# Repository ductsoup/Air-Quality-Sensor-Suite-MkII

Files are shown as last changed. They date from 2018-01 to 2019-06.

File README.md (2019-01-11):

# Air-Quality-Sensor-Suite-MkII
A simple, inexpensive but accurate air quality monitor built around a Raspberry Pi 3 or Pi Zero W with the ability to inteface with industrial SCADA systems via Modbus TCP. With a few additional lines of code in the main loop it's relatively straightfoward to push the entire collected and calculated data set to an IoT/IIoT MQTT broker.

The two attached sensors read temperature, pressure, humidity, VOC and particulates. The script then derives other quantities such as dewpoint, air density, air quality index (AQI), NowCast and indoor air quality (IAQ).

## Usage Notes
While tested on Raspian Jessie and Python3 it will probably run on older versions of Python or newer versions of Raspbian with little or no modification.

```sudo python3 main.py```

By default the Modbus slave binds to all active connections. Root privledges are
requred because we're serving on the Modbus default port 502.

As a practical matter you'll probably want to set this script up to run as a service 
with systemd rather than using cron or rc.local. 

* https://www.raspberrypi.org/documentation/linux/usage/systemd.md
* https://github.com/joan2937/pigpio/tree/master/util

## Requirements

### Modbus-tk
https://github.com/ljean/modbus-tk

This provides the MODBUS TCP transport. Values are mapped into holding registeres encoded as an [IEEE 754 32-bit float](https://en.wikipedia.org/wiki/IEEE_754).

If you'd like to send the data to an MQTT broker instead just install Paho and modify the relevant sections in ```main.py```.

### Pigpio
http://abyz.me.uk/rpi/pigpio/index.html

This is used to bitbang GPIO 18 to interface with the PMS5003, just pick another pin if that's inconvenient. 

### Pimoroni BME680
https://github.com/pimoroni/bme680

I'm using an Adafruit breakout board with the Pimoroni library for their breakout board. Both boards are functionally identical, the only relevant difference between them (other than the pinouts) is the default I2C address so I need to specify that when I create the instance.

```bme680.BME680(i2c_addr=0x77)```

## Sensors/Interfaces
### BME680 (I2C) 
* [datasheet](https://cdn-shop.adafruit.com/product-files/3660/BME680.pdf)
* https://shop.pimoroni.com/products/bme680
* https://www.adafruit.com/product/3660

### PMS5003 (software serial)
* [datasheet](https://cdn-shop.adafruit.com/product-files/3686/plantower-pms5003-manual_v2-3.pdf)
* https://www.adafruit.com/product/3686

The original design used a PPD42NS or SM-PWM-01A particle sensor which was difficult to interface with anything but an embedded device because you really need hardware interrupts to count the particles in real time. The PMS5003 does all that internally, reports in engineering units and provides a 3.3V compatible serial output making it very easy to interface with a Raspberry Pi.

![wiring](/img/aqm-mk-II_bb1.jpg)

## MODBUS Register Map
### System
```
40001   Quality Control (3.14159265359)
```
### Measured BME680
```
40003   Temperature (C)
40005   Temperature (F)
40007   Pressure (hPa)
40009   Pressure (inHg)
40011   Relative Humidity (%)
40013   VOC (kOhm)
```
### Measured PMS5003
```
40015   PM1.0 standard (ug/m3)
40017   PM2.5 standard (ug/m3)
40019   PM10 standard (ug/m3)
40021   PM1.0 environmental (ug/m3)
40023   PM2.5 environmental (ug/m3)
40025   PM10 environmental (ug/m3)
40027   Particles > 0.3 um / 0.1L air
40029   Particles > 0.5 um / 0.1L air
40031   Particles > 1.0 um / 0.1L air
40033   Particles > 2.5 um / 0.1L air
40035   Particles > 5.0 um / 0.1L air
40037   Particles > 50  um / 0.1L air
```
### Derived
```
40039   Dewpoint (C)
40041   Dewpoint (F)
40043   Partial pressure water vapor (hPa)
40045   Partial pressure dry air (hPa)
40047   Air density (kg/m3)
40049   Air density (lb/ft3)

40051   AQI (0-500, -1 if unavailable)
40053   PM25 contribution to AQI
40055   PM10 contribution to AQI
40057   AQI NowCast
40059   PM25 contribution to AQI NowCast
40061   PM10 contribution to AQI NowCast
40063   AQI Current (1 minute)
40065   PM25 contribution to AQI Current
40067   PM10 contribution to AQI Current

40069   PM01 60 second average (ug/m3)
40071   PM01 60 minute average (ug/m3)
40073   PM01 24 hour average (ug/m3)
40075   PM25 60 second average (ug/m3)
40077   PM25 60 minute average (ug/m3)
40079   PM25 24 hour average (ug/m3)
40081   PM10 60 second average (ug/m3)
40083   PM10 60 minute average (ug/m3)
40085   PM10 24 hour average (ug/m3)

40087   IAQ (0-100, -1 if unavailable)
40089   RH contribution to IAQ
40091   VOC contribution to IAQ
40093   VOC 60 second average (kOhm)
40095   VOC 60 minute average (kOhm)
40097   VOC 24 hour average (kOhm)
```
## Classes
### Unit Conversion
Weather calculations are notorious for mixing SI and imperial units and combining constants making them difficult to follow. Even with SI it's not uncommon to switch back and forth between units like Celsius and Kelvin.

To simplify, pass an SI value (Celsius) when you initialize a unit conversion object. You can then retrieve the value in any relavant unit, SI or imperial (Celsius, Kelvin, Fahrenheit or Rankine).

```python
Temperature = T(25)
print(Temperature.C, Temperature.K, Temperature.F, Temperature.R)
```
There are also unit conversion classes for pressure and density.

### Cascadable Running/Retained Average 
The first challenge is that AQI requires a 24 hour average measurement and embedded systems can rest at any time. The second is if you're sampling at 1 second intervals that's 86400 (60*60*24) samples to average.

This class allows you to define a one second sample aggregated to a one minute average, cascaded to a one hour average, cascaded to a one day average (lather, rise and repeat for weekly, monthly or annual), writing the results to storage and reloading as necessary between resets. In the 24 hour example it only retains 144 values (60+60+24). As you're building history to whatever average you've defined, the class will provide the best approximation available.

The caveat with SD storage is you have a finite number of write cycles. To start I've chosen the compromise of writing hourly. If the reset is short duration, it won't significantly compromise the results. 

```python
pm25_24h = CRR_AVG(24, jfile = "pm25_24h")    # daily average (retained)
pm25_60m = CRR_AVG(60, pm25_24h)              # hourly average
pm25_60s = CRR_AVG(60, pm25_60m)              # minutely average
```

### Derived Weather Variables
This class approximates dewpoint and air density from the BME680 observations.

### AQI Air Quality Index and NowCast
The AQI class implments [Air Quality Index](https://en.wikipedia.org/wiki/Air_quality_index) and 
[NowCast](https://en.wikipedia.org/wiki/NowCast_(air_quality_index)) calculations. Not defined in those standards but useful for what I'm doing I've also implemented a one minute AQI. 

Currently the class implements only the PM2.5 and PM10 components of AQI. It is however, designed to be easily extended to include O3, CO, SO2 and No2.

### IAQ Indoor Air Quality
There isn't a generally accepted standard for indoor air quality that I am aware of however, Bosch has provided a closed source binary called [BSEC](https://www.bosch-sensortec.com/bst/products/all_products/BSEC) for use with the BME680 to do that calculation. Based on the description in the datasheet they're likely doing something similar to what is implemented in the IAQ class. 

## Enclosure
For the enclosure I customized [The Ultimate box maker](https://www.thingiverse.com/thing:1264391) from Thingiverse.

My 3D printer didn't do such a good job on the 2.05mm tap drill holes for mounting the Pi Zero W and I'm guessing most others won't either so I opened those up with a 5/64 (1.98mm) drill, ran a M2.5x0.45 tap through by hand then finished up with some M2.5 nylon screws (Amazon is your friend for fine tools and supplies like this).

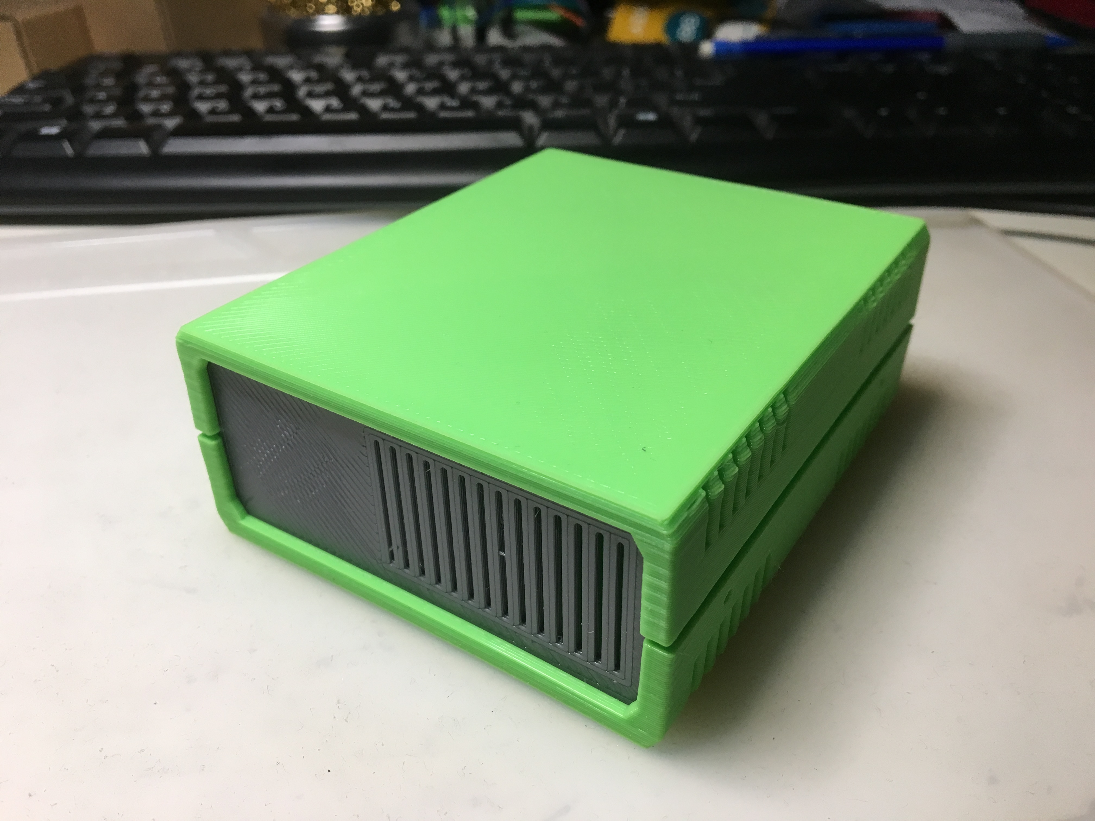
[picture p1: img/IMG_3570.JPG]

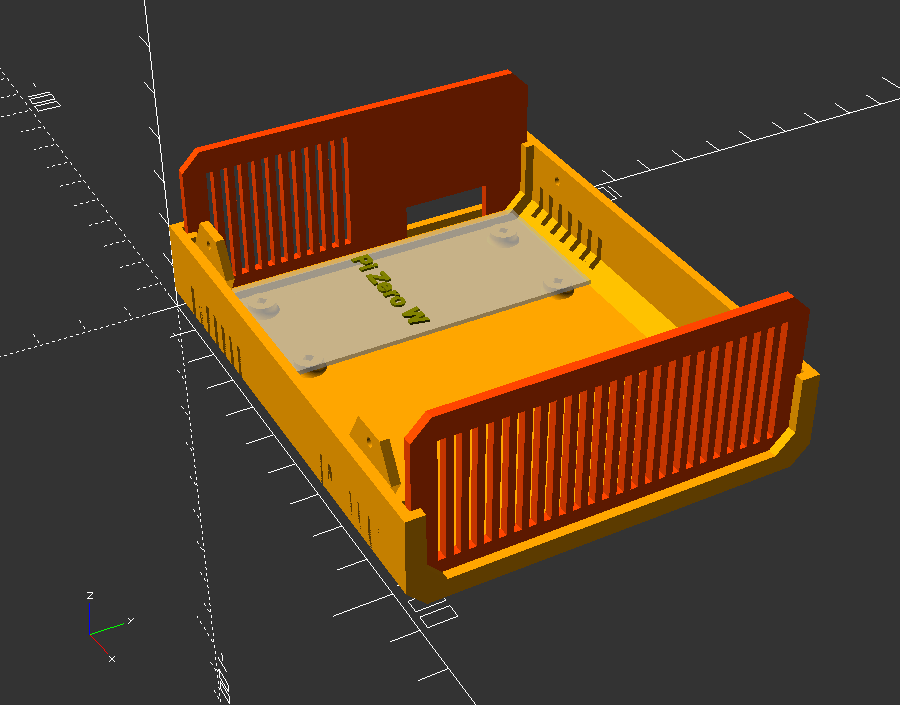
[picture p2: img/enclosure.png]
enclosure


## Rev 1 10/09/2018
I added support for the SGP30 VOC and eCO2 sensor.

### SGP30 (I2C) 
* [datasheet](https://cdn-learn.adafruit.com/assets/assets/000/050/058/original/Sensirion_Gas_Sensors_SGP30_Datasheet_EN.pdf)
* https://www.adafruit.com/product/3709

I also added Eagle files for a custom Pi Hat which I've built a couple times so it's verified good (Sunstone).

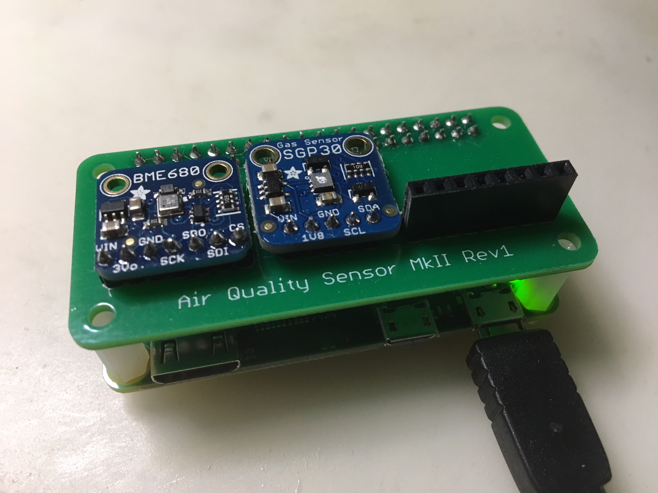
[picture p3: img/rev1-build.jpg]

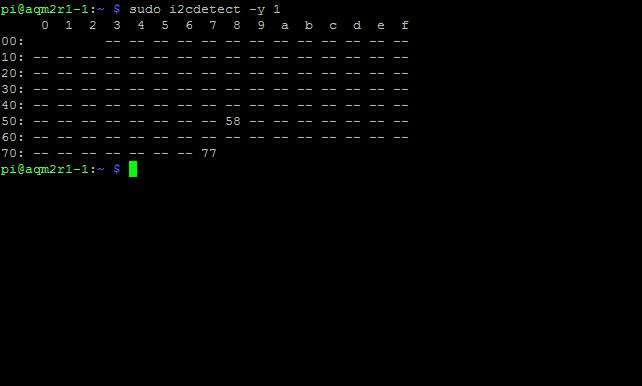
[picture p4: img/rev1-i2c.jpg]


The perma-proto board construction above works great but it's a little tedious and somewhat error prone to build. Populating the custom PCB is easy. It's actually taking far longer to 3D print the enclosure than do the build and configure the software on the Pi Zero W.

```
40099   CO2 equivalent (ppm)
40101   CO2 equivalent 60 second average (ppm)
40103   CO2 equivalent 60 minute average (ppm)
40105   CO2 equivalent 24 hour average (ppm)
40107   VOC (ppb)
40109   VOC 60 second average (ppb)
40111   VOC 60 minute average (ppb)
40113   VOC 24 hour average (ppb)  
40115   Absolute Humidity (g/m^3)
```

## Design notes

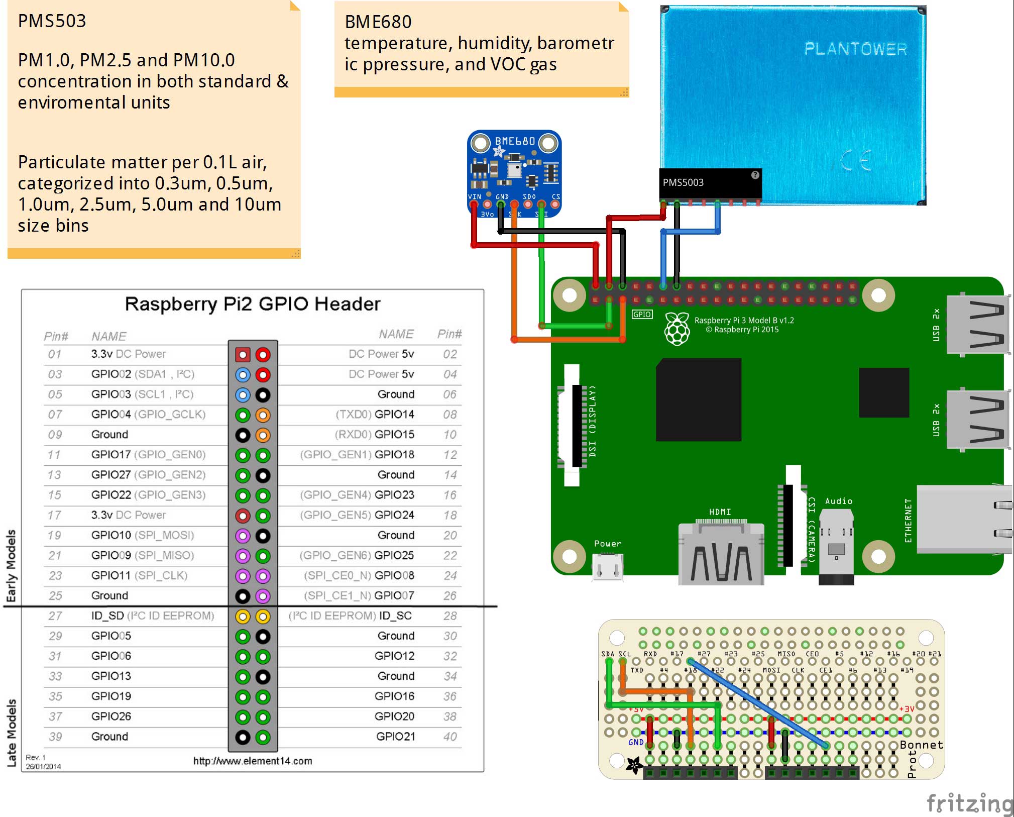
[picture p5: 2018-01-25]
img/aqm-mk-II_bb1.jpg

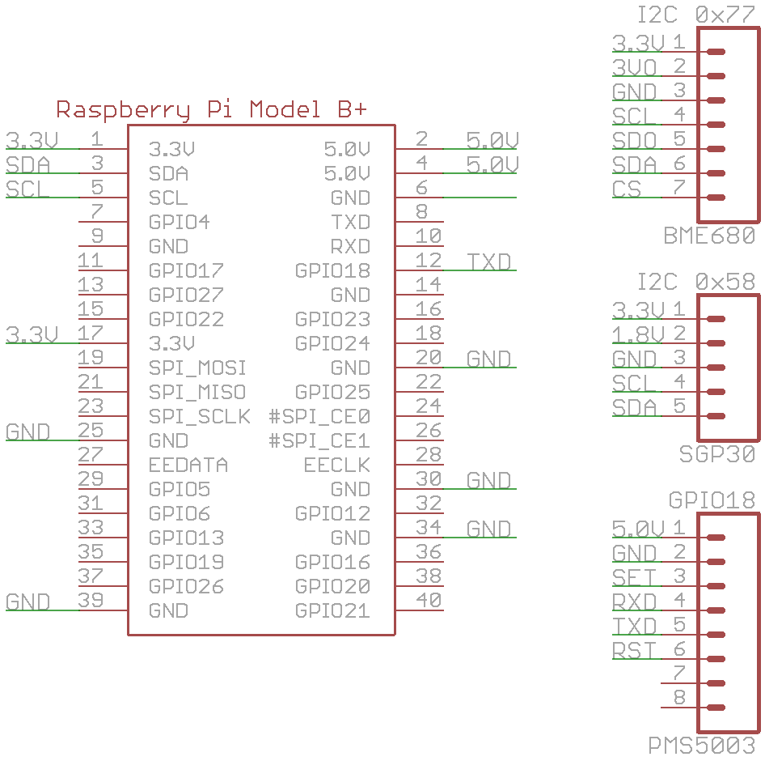
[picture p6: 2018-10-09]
rev1/pcb/sch.png

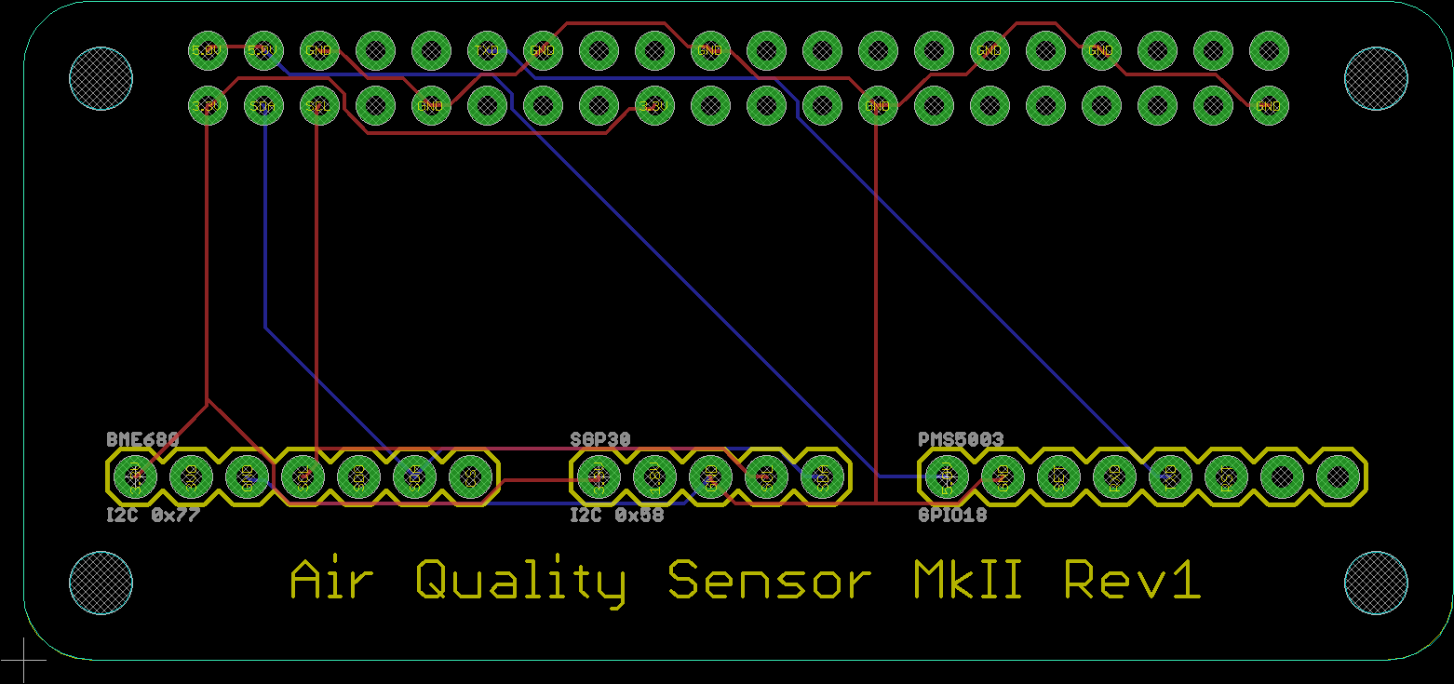
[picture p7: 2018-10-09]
rev1/pcb/brd.png

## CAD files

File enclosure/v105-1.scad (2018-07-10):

/*//////////////////////////////////////////////////////////////////
              -    FB Aka Heartman/Hearty 2016     -                   
              -   http://heartygfx.blogspot.com    -                  
              -       OpenScad Parametric Box      -                     
              -         CC BY-NC 3.0 License       -                      
////////////////////////////////////////////////////////////////////                                                                                                             
12/02/2016 - Fixed minor bug 
28/02/2016 - Added holes ventilation option                    
09/03/2016 - Added PCB feet support, fixed the shell artefact on export mode. 
21/11/2017 by Richard Pillay - Added ability to have up to 4 PCBs

*/////////////////////////// - Info - //////////////////////////////

// All coordinates are starting as integrated circuit pins.
// From the top view :

//   CoordD           <---       CoordC
//                                 ^
//                                 ^
//                                 ^
//   CoordA           --->       CoordB


////////////////////////////////////////////////////////////////////


////////// - Paramètres de la boite - Box parameters - /////////////

/* [Box dimensions] */
// - Longueur - Length  
  Length        = 105;       
// - Largeur - Width
  Width         = 85;                     
// - Hauteur - Height  
  Height        = 40;  
// - Epaisseur - Wall thickness  
  Thick         = 2;//[2:5]  
  
/* [Box options] */
// - Diamètre Coin arrondi - Filet diameter  
  Filet         = 4;//[0.1:12] 
// - lissage de l'arrondi - Filet smoothness  
  Resolution    = 4;//[1:100] 
// - Tolérance - Tolerance (Panel/rails gap)
  m             = 0.9;
// Pieds PCB - PCB feet (x4 for each) 
  PCB01Feet       = 1;// [0:No, 1:Yes]
  PCB02Feet       = 0;// [0:No, 1:Yes]
  PCB03Feet       = 0;// [0:No, 1:Yes]
  PCB04Feet       = 0;// [0:No, 1:Yes]
// - Decorations to ventilation holes
  Vent          = 1;// [0:No, 1:Yes]
// - Decoration-Holes width (in mm)
  Vent_width    = 1.5;   


  
/* [PCB_Feet] */
//All dimensions are from the center foot axis

PCB01Text = "     Pi Zero W";
// - Coin bas gauche - Low left corner X position
PCB01PosX         = 0;
// - Coin bas gauche - Low left corner Y position
PCB01PosY         = 2;
// - Longueur PCB01 - PCB01 Length
PCB01Length       = 23;
// - Largeur PCB01 - PCB01 Width
PCB01Width        = 58;
// - Heuteur pied - Feet height
PCB01FootHeight      = 5;
// - Diamètre pied - Foot diameter
PCB01FootDiam         = 6;
// - Diamètre trou - Hole diameter
PCB01FootHole        = 2.5;  

PCB02Text = "PMS";
PCB02PosX           = 35;
PCB02PosY           = 6;
PCB02Length         = 38;
PCB02Width          = 50;
PCB02FootHeight     = 5;
PCB02FootDiam      = 4;
PCB02FootHole        = 2;  
  
PCB03Text = "PCB3";
PCB03PosX           = 95;
PCB03PosY         = 84;
PCB03Length       = 50;
PCB03Width        = 55;
PCB03FootHeight      = 10;
PCB03FootDiam         = 8;
PCB03FootHole        = 3;  
  
PCB04Text = "PCB4";
PCB04PosX         = 75;
PCB04PosY         = 6;
PCB04Length       = 70;
PCB04Width        = 50;
PCB04FootHeight      = 10;
PCB04FootDiam         = 8;
PCB04FootHole        = 3;  
  

/* [STL element to export] */
//Coque haut - Top shell
TShell          = 0;// [0:No, 1:Yes]
//Coque bas- Bottom shell
BShell          = 0;// [0:No, 1:Yes]
//Panneau avant - Front panel
FPanL           = 1;// [0:No, 1:Yes]
//Panneau arrière - Back panel  
BPanL           = 1;// [0:No, 1:Yes]


  
/* [Hidden] */
// - Couleur coque - Shell color  
Couleur1        = "Orange";       
// - Couleur panneaux - Panels color    
Couleur2        = "OrangeRed";    
// Thick X 2 - making decorations thicker if it is a vent to make sure they go through shell
Dec_Thick       = Vent ? Thick*2 : Thick; 
// - Depth decoration
Dec_size        = Vent ? Thick*2 : 0.8;


/////////// - Boitier générique bord arrondis - Generic rounded box - //////////

module RoundBox($a=Length, $b=Width, $c=Height){// Cube bords arrondis
                    $fn=Resolution;            
                    translate([0,Filet,Filet]){  
                    minkowski (){                                              
                        cube ([$a-(Length/2),$b-(2*Filet),$c-(2*Filet)], center = false);
                        rotate([0,90,0]){    
                        cylinder(r=Filet,h=Length/2, center = false);
                            } 
                        }
                    }
                }// End of RoundBox Module

      
////////////////////////////////// - Module Coque/Shell - //////////////////////////////////         

module Coque(){//Coque - Shell  
    Thick = Thick*2;  
    difference(){    
        difference(){//sides decoration
            union(){    
                     difference() {//soustraction de la forme centrale - Substraction Fileted box
                      
                        difference(){//soustraction cube median - Median cube slicer
                            union() {//union               
                            difference(){//Coque    
                                RoundBox();
                                translate([Thick/2,Thick/2,Thick/2]){     
                                        RoundBox($a=Length-Thick, $b=Width-Thick, $c=Height-Thick);
                                        }
                                        }//Fin diff Coque                            
                                difference(){//largeur Rails        
                                     translate([Thick+m,Thick/2,Thick/2]){// Rails
                                          RoundBox($a=Length-((2*Thick)+(2*m)), $b=Width-Thick, $c=Height-(Thick*2));
                                                          }//fin Rails
                                     translate([((Thick+m/2)*1.55),Thick/2,Thick/2+0.1]){ // +0.1 added to avoid the artefact
                                          RoundBox($a=Length-((Thick*3)+2*m), $b=Width-Thick, $c=Height-Thick);
                                                    }           
                                                }//Fin largeur Rails
                                    }//Fin union                                   
                               translate([-Thick,-Thick,Height/2]){// Cube à soustraire
                                    cube ([Length+100, Width+100, Height], center=false);
                                            }                                            
                                      }//fin soustraction cube median - End Median cube slicer
                               translate([-Thick/2,Thick,Thick]){// Forme de soustraction centrale 
                                    RoundBox($a=Length+Thick, $b=Width-Thick*2, $c=Height-Thick);       
                                    }                          
                                }                                          


                difference(){// wall fixation box legs
                    union(){
                        translate([3*Thick +5,Thick,Height/2]){
                            rotate([90,0,0]){
                                    $fn=6;
                                    cylinder(d=16,Thick/2);
                                    }   
                            }
                            
                       translate([Length-((3*Thick)+5),Thick,Height/2]){
                            rotate([90,0,0]){
                                    $fn=6;
                                    cylinder(d=16,Thick/2);
                                    }   
                            }

                        }
                            translate([4,Thick+Filet,Height/2-57]){   
                             rotate([45,0,0]){
                                   cube([Length,40,40]);    
                                  }
                           }
                           translate([0,-(Thick*1.46),Height/2]){
                                cube([Length,Thick*2,10]);
                           }
                    } //Fin fixation box legs
            }

        union(){// outbox sides decorations
            
            for(i=[0:Thick:Length/4]){
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

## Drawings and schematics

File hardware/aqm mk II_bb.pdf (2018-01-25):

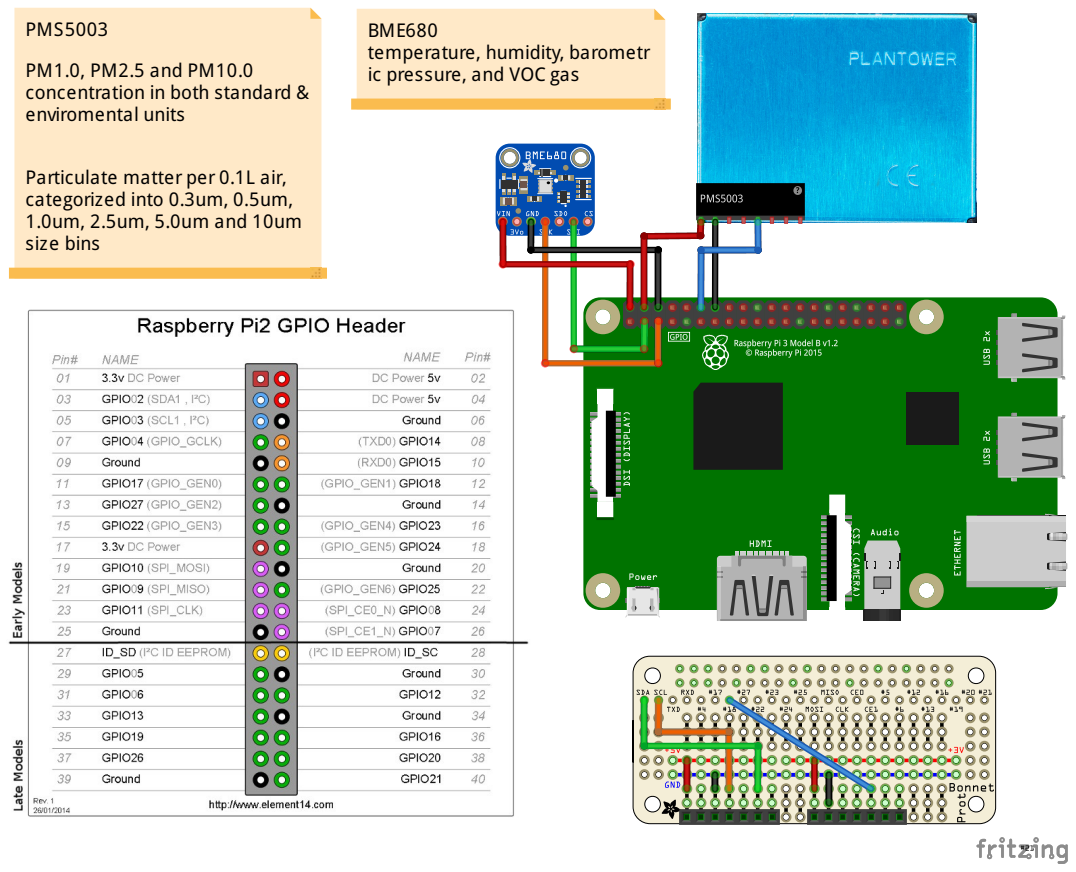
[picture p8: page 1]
PMS5003

BME680
temperature, humidity, barometr
ic pressure, and VOC gas

PM1.0, PM2.5 and PM10.0
concentration in both standard &
enviromental units

Particulate matter per 0.1L air,
categorized into 0.3um, 0.5um,
1.0um, 2.5um, 5.0um and 10um
size bins

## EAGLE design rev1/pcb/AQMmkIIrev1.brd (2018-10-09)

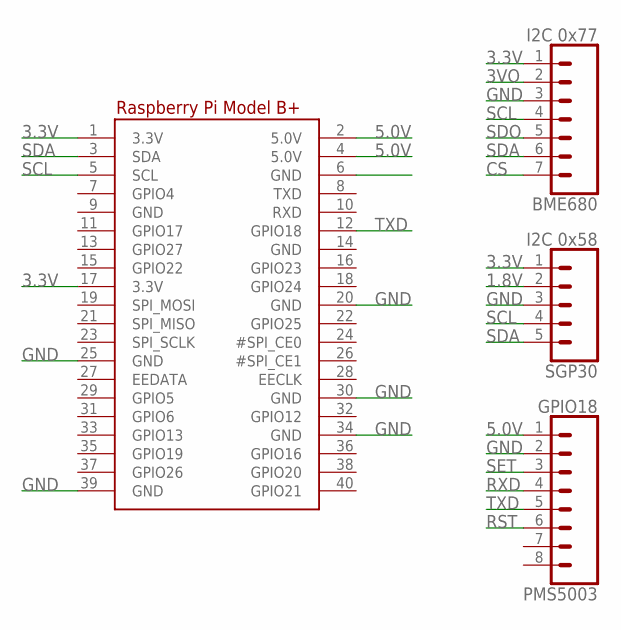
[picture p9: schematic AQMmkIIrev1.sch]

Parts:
BME680: I2C 0x77; 1X07
PMS5003: GPIO18; 1X08
RPI1: RASPBERRYPI_BPLUS_BONNETNODIM; PI_BONNET_NODIM
SGP30: I2C 0x58; 1X05

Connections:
1.8V: SGP30.2
3.3V: BME680.1, RPI1.1 (3.3V), RPI1.17 (3.3V), SGP30.1
3VO: BME680.2
5.0V: PMS5003.1, RPI1.2 (5.0V), RPI1.4 (5.0V)
CS: BME680.7
GND: BME680.3, PMS5003.2, RPI1.6 (GND), RPI1.9 (GND), RPI1.14 (GND), RPI1.20 (GND), RPI1.25 (GND), RPI1.30 (GND), RPI1.34 (GND), RPI1.39 (GND), SGP30.3
RST: PMS5003.6
RXD: PMS5003.4
SCL: BME680.4, RPI1.5 (SCL), SGP30.4
SDA: BME680.6, RPI1.3 (SDA), SGP30.5
SDO: BME680.5
SET: PMS5003.3
TXD: PMS5003.5, RPI1.12 (GPIO18)

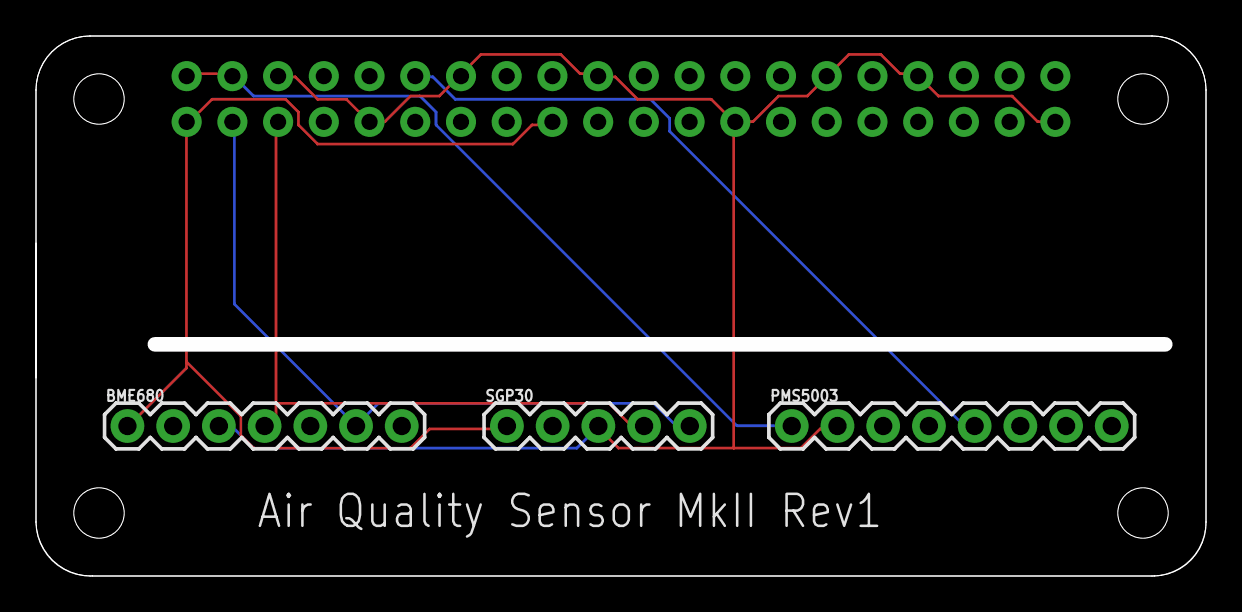
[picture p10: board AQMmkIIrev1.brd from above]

Board: 2 copper layers, 65.0 x 30.0 mm, 4 parts (0 on the bottom side), 6 nets.

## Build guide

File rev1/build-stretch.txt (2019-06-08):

# (flash Stretch image)
# (add ssh file to root directory)
# (add wpa_supplicant.conf file to root directory)
# 192.168.x.143

passwd

sudo apt-get update
sudo apt-get -y upgrade
sudo apt-get -y dist-upgrade
sudo apt-get -y autoclean
sudo apt-get -y autoremove

sudo apt-get update
sudo apt-get -y install git python3-setuptools
sudo apt-get -y install python3-pip
sudo apt-get -y install python3-smbus i2c-tools

sudo pip3 install RPi.GPIO
sudo pip3 install adafruit-circuitpython-bme680
sudo pip3 install adafruit-circuitpython-sgp30
sudo pip3 install modbus-tk
sudo pip3 install adafruit-io

sudo raspi-config
# Network Options / N1 Hostname
# Localisation Options / Change Wi-fi Country
# Localisation Options / Change Timezone
# Interfacing Options / P5 I2C (enable)
# Advanced Options / A1 Expand Filesystem
# (finish and reboot)

rm pigpio.zip
sudo rm -rf PIGPIO
wget abyz.me.uk/rpi/pigpio/pigpio.zip
unzip pigpio.zip
cd PIGPIO
make
sudo make install
sudo ./x_pigpio
sudo crontab -e
#@reboot              /usr/local/bin/pigpiod
sudo reboot

htop
# confirm pigpiod started at boot
sudo i2cdetect -y 1
# Confirm the BME680 (0x77) and SGP30 (0x58) are available

git clone https://github.com/ductsoup/Air-Quality-Sensor-Suite-MkII.git
cd Air-Quality-Sensor-Suite-MkII/rev1/software

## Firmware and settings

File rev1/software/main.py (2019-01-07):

#!/usr/bin/env python -u
"""
Air Quality Monitor Mk II rev 1
"""

import sys
import time
from math import *

import modbus_tk
import modbus_tk.defines as cst
from modbus_tk import modbus_tcp

import bme680
import adafruit_sgp30
import board
import busio
import pigpio

from derived_wx import *
from crr_avg import *

import struct

""" 
MODBUS helper for floating point holding registers 
"""
def mb_set(addr, val):
    """ Set a pair of MODBUS holding registers with an encoded IEEE 754 32-bit float """
    j = struct.unpack('<HH',struct.pack('<f', float(val)))
    slave_1.set_values('ro', addr, j)
    return val

"""
Extend the Adafruit SGP30 class to add compensation for temperature and humidity
"""
class sgp30hc(adafruit_sgp30.Adafruit_SGP30):
    AH = 0  # Absolute humidity (g/m^3)
    def set_humidity(self, t, RH):
        """Set the humitity compensation using temperature (C) and RH (0-100)"""
        self.AH = 216.7 * (((RH / 100) * 6.112 * exp((17.62 * t) / (243.12 + t))) / (273.15 + t))    
        if self.AH > 256:
            raise RuntimeError('Invalid humidity compensation')
        buffer = []
        arr = [int(self.AH), floor(256 * (self.AH - int(self.AH)))]
        arr.append(self._generate_crc(arr))
        buffer += arr
        print("**** Temperature = %3.2f (C), RH = %3.2f (%%), AH = %3.2f (g/m^3), HC = 0x%02x%02x" % (t, RH, self.AH, arr[0], arr[1]))
        return self._run_profile(["set_humidity", [0x20, 0x61] + buffer, 0, 0.01])

    def disable_humidity(self):
        """Disable humidity compensation"""
        buffer = []
        arr = [0x00, 0x00]
        arr.append(self._generate_crc(arr))
        buffer += arr
        return self._run_profile(["disable_humidity", [0x20, 0x61] + buffer, 0, 0.01])

"""
Main loop
"""
if __name__ == "__main__":
    try:
        """ Initialize the MODBUS TCP slave """        
        mb_start = 40001
        mb_len = 125
        server = modbus_tcp.TcpServer(address='0.0.0.0')
        server.start()
        slave_1 = server.add_slave(1)
        slave_1.add_block('ro', cst.HOLDING_REGISTERS, mb_start, mb_len)
        # Example: 
        # 
        # -0            First reference is 0 (PDU addressing) instead 1
        # -1            Poll only once only, otherwise every poll rate interval
        # -m tcp        MODBUS/TCP protocol (default otherwise)
        # -t 4:float    32-bit float data type in output (holding) register table
        # -r #          Start reference (1-65536, 100 is default)
        # -c #          Number of values to read (1-125, 1 is default)
        #
        # modpoll -0 -1 -m tcp -t 4:float -r 40001 -c 58 192.168.x.x
    
        """ Initialize the BME680 """
        s1 = bme680.BME680(i2c_addr=0x77)
        s1.set_humidity_oversample(bme680.OS_2X)
        s1.set_pressure_oversample(bme680.OS_4X)
        s1.set_temperature_oversample(bme680.OS_8X)
        s1.set_filter(bme680.FILTER_SIZE_3)
        s1.set_gas_status(bme680.ENABLE_GAS_MEAS)
        s1.set_gas_heater_temperature(320)
        s1.set_gas_heater_duration(150)
        s1.select_gas_heater_profile(0)

        """ Initialize the PMS5003 """
        RX=18
        s2 = pigpio.pi()
        s2.set_mode(RX, pigpio.INPUT)
        s2.bb_serial_read_open(RX, 9600, 8)  

        """ Initialize the SGP30 """
        i2c = busio.I2C(board.SCL, board.SDA, frequency=100000)
        s3 = sgp30hc(i2c)
        print("SGP30 serial #", [hex(i) for i in s3.serial])
        s3.iaq_init()
        s3.set_iaq_baseline(0x8895, 0x8a44)
        elapsed_sec = 0

        """ Initialize running average for PM1.0, PM2.5, PM10, RH and VOC """
        pm01_24h = CRR_AVG(24, jfile = "pm01_24h")    # daily average (retained)
        pm01_60m = CRR_AVG(60, pm01_24h)              # hourly average 
        pm01_60s = CRR_AVG(60, pm01_60m)              # minutely average
        co2e_24h = CRR_AVG(24, jfile = "co2e_24h")    # daily average (retained)
        co2e_60m = CRR_AVG(60, co2e_24h)              # hourly average 
        co2e_60s = CRR_AVG(60, co2e_60m)              # minutely average
        tvoc_24h = CRR_AVG(24, jfile = "tvoc_24h")    # daily average (retained)
        tvoc_60m = CRR_AVG(60, tvoc_24h)              # hourly average 
        tvoc_60s = CRR_AVG(60, tvoc_60m)              # minutely average

        """ Initialize AQI object """ 
        aqi = AQI()   
        iaq = IAQ()   

        print("Ready")

        while True:
            """
            40001   Quality Control (3.14159265359)            
            """
            mb_set(40001, pi)                                      

            """ Poll the BME680 """
            if s1.get_sensor_data():
                RH = s1.data.humidity
                wx = WX(T(s1.data.temperature), P(100.0*s1.data.pressure), RH)
                iaq.rh(RH)                        

                """
                40003   Temperature (C)
                40005   Temperature (F)
                40007   Pressure (hPa)
                40009   Pressure (inHg)
                40011   Relative Humidity (%)  
                40013   VOC (kOhm)
                """               
                mb_set(40003, wx.t.C)                                
                mb_set(40005, wx.t.F)                                
                mb_set(40007, wx.p.hPa)                              
                mb_set(40009, wx.p.inHg)                             
                mb_set(40011, wx.RH)

                """
                40039   Dewpoint (C)
                40041   Dewpoint (F)
                40043   Partial pressure water vapor (hPa)
                40045   Partial pressure dry air (hPa)
                40047   Air density (kg/m3)
                40049   Air density (lb/ft3)
                """
                mb_set(40039, wx.td.C)                               
                mb_set(40041, wx.td.F)                              
                mb_set(40043, wx.Pv.hPa)                             
                mb_set(40045, wx.Pd.hPa)                             
                mb_set(40047, wx.Rho.kgperm3)                        
                mb_set(40049, wx.Rho.lbperft3)    
                
                if s1.data.heat_stable:
                    VOC = s1.data.gas_resistance/1000.0
                    mb_set(40013, VOC)    
                    iaq.voc(VOC)

                    """
                    40091   VOC contribution to IAQ
                    40093   VOC 60 second average (kOhm)
                    40095   VOC 60 minute average (kOhm)
                    40097   VOC 24 hour average (kOhm)
                    """
                    mb_set(40091, iaq.IAQ_VOC)
                    mb_set(40093, iaq.voc_60s.avg)
                    mb_set(40095, iaq.voc_60m.avg or iaq.voc_60s.avg)
                    mb_set(40097, iaq.voc_24h.avg or iaq.voc_60m.avg or iaq.voc_60s.avg)

                """
                40087   IAQ
                40089   RH contribution to IAQ
                """
                mb_set(40087, iaq.IAQ)
                mb_set(40089, iaq.IAQ_RH)

            """ Retrieve a packet from the PMS5003 """
            (count, data) = s2.bb_serial_read(RX)
            if count == 32 and data[0] == 0x42 and data[1] == 0x4d:
                s = (struct.Struct(">"+"H"*16)).unpack(data)
                pm01_60s.y(float(s[2]))
                aqi.pm25(float(s[3]))
                aqi.pm10(float(s[4]))

                """
                40015   PM1.0 standard (ug/m3)
                40017   PM2.5 standard (ug/m3)
                40019   PM10 standard (ug/m3)
                40021   PM1.0 environmental (ug/m3)
                40023   PM2.5 environmental (ug/m3)
                40025   PM10 environmental (ug/m3)
                40027   Particles > 0.3 um / 0.1L air
                40029   Particles > 0.5 um / 0.1L air
                40031   Particles > 1.0 um / 0.1L air
                40033   Particles > 2.5 um / 0.1L air
                40035   Particles > 5.0 um / 0.1L air
                40037   Particles > 50  um / 0.1L air
                """
                for i in range(0,12):                    
                    mb_set(40015 + 2 * i, float(s[i + 2]))

                """
                40051   AQI
                40053   PM25 contribution to AQI
                40055   PM10 contribution to AQI
                """
                mb_set(40051, aqi.AQI)
                mb_set(40053, aqi.AQI_PM25)
                mb_set(40055, aqi.AQI_PM10)
                
                """
                40057   AQI NowCast
                40059   PM25 contribution to AQI NowCast
                40061   PM10 contribution to AQI NowCast
                """
                mb_set(40057, aqi.AQI_NOWCAST)
                mb_set(40059, aqi.AQI_PM25_NOWCAST)
                mb_set(40061, aqi.AQI_PM10_NOWCAST)

                """
                40063   AQI Current
                40065   PM25 contribution to AQI Current
                40067   PM10 contribution to AQI Current
                """
                mb_set(40063, aqi.AQI_CURRENT)              
                mb_set(40065, aqi.AQI_PM25_CURRENT)
                mb_set(40067, aqi.AQI_PM10_CURRENT)

                """
                40069   PM01 60 second average (ug/m3)
                40071   PM01 60 minute average (ug/m3)
                40073   PM01 24 hour average (ug/m3)
                40075   PM25 60 second average (ug/m3)
                40077   PM25 60 minute average (ug/m3)
                40079   PM25 24 hour average (ug/m3)
                40081   PM10 60 second average (ug/m3)
                40083   PM10 60 minute average (ug/m3)
                40085   PM10 24 hour average (ug/m3)
                """
                mb_set(40069, pm01_60s.avg)
                mb_set(40071, pm01_60m.avg or pm01_60s.avg)
                mb_set(40073, pm01_24h.avg or pm01_60m.avg or pm01_60s.avg)
                mb_set(40075, aqi.pm25_60s.avg)
                mb_set(40077, aqi.pm25_60m.avg or aqi.pm25_60s.avg)
                mb_set(40079, aqi.pm25_24h.avg or aqi.pm25_60m.avg or aqi.pm25_60s.avg)
                mb_set(40081, aqi.pm10_60s.avg)
                mb_set(40083, aqi.pm10_60m.avg or aqi.pm10_60s.avg)
                mb_set(40085, aqi.pm10_24h.avg or aqi.pm10_60m.avg or aqi.pm10_60s.avg)

                """
                SGP30 serial # ['0x0', '0x64', '0xef7b']
                Correct for temperature and humidity about once a minute
                """ 
                if (elapsed_sec > 59):
                    elapsed_sec = 0
                    try:
                        s3.set_humidity(wx.t.C, wx.RH)
                        #print("**** Baseline values set: co2eq = 0x%x, tvoc = 0x%x" % (s3.baseline_co2eq, s3.baseline_tvoc))
                    except:
                        s3.disable_humidity()
                else:
                    elapsed_sec += 1

                """              
                40099   CO2 equivalent (ppm)
                40101   CO2 equivalent 60 second average (ppm)
                40103   CO2 equivalent 60 minute average (ppm)
                40105   CO2 equivalent 24 hour average (ppm)
                40107   VOC (ppb)
                40109   VOC 60 second average (ppb)
                40111   VOC 60 minute average (ppb)
                40113   VOC 24 hour average (ppb)  
                40115   Absolute Humidity (g/m^3)
                """
                co2e_60s.y(mb_set(40099, s3.co2eq))
                mb_set(40101, co2e_60s.avg)
                mb_set(40103, co2e_60m.avg or co2e_60s.avg)
                mb_set(40105, co2e_24h.avg or co2e_60m.avg or co2e_60s.avg)

                tvoc_60s.y(mb_set(40107, s3.tvoc))
                mb_set(40109, tvoc_60s.avg)
                mb_set(40111, tvoc_60m.avg or tvoc_60s.avg)
                mb_set(40113, tvoc_24h.avg or tvoc_60m.avg or tvoc_60s.avg)

                mb_set(40115, s3.AH)
                #print("co2eq = %d ppm \t tvoc = %d ppb" % (s3.co2eq, s3.tvoc))

            time.sleep(1)

    finally:
        s2.bb_serial_read_close(RX)
        s2.stop()
        server.stop()

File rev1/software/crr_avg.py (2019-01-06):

import json
class CRR_AVG:
    """ Cascadable running/retained average class """
    buf = None      # circular buffer of samples to average
    buf_i = 0       # current buffer index
    buf_n = None    # buffer size (number of samples to average)
    cas = None      # (optional) cascade counter object
    jfile = None    # (optional) JSON file name
    avg = None      # running average

    def __init__(self, buf_n, cas = None, jfile = None):
        """ Constructor """
        self.buf_n = buf_n
        self.cas = cas
        self.jfile = jfile
        self.reset()
        if jfile != None:
            try:
                with open("%s.json" % self.jfile) as fd:
                    self.buf_i, self.buf = json.load(fd)
                #print("loaded %f values from %s" % (len(self.buf), self.jfile))
            except:
                pass
    
    def y(self, val):
        """ Add a sample to the circular buffer and return the running average """
        if len(self.buf) < self.buf_n:
            self.buf.append(val)
        else:
            self.buf[self.buf_i] = val
        self.buf_i += 1
        self.avg = sum(self.buf) / len(self.buf)
        if self.buf_i == self.buf_n:
            self.buf_i = self.buf_i % self.buf_n            
            if self.cas != None:  
                self.cas.y(self.avg)
            self.dump()            
        return self.avg
    
    def dump(self):
        """ If a filename was provided serialize to a JSON file """
        if self.jfile != None:      
            with open("%s.json" % self.jfile, 'w') as fd:
                json.dump([self.buf_i, self.buf], fd)        
        if self.cas != None: 
            self.cas.dump()

    def set(self, i, buf):
        """ Initialize with previously saved values """
        self.buf = buf
        self.buf_i = i
        self.avg = None if len(buf) == 0 else (sum(buf) / len(buf))

    def reset(self):
        """ Reset the object """
        self.set(0, [])

if __name__ == "__main__":

    import random

    """
    Calculate a 24 hour average at 1 sample per second (60*60*24 = 86400 values)
    using a reasonable number of variables (60+60+24 = 144 values).  
    """
    ravg_24h = CRR_AVG(24, jfile = "day")       # daily average bin (retained)
    ravg_60m = CRR_AVG(60, ravg_24h)            # hourly average bin
    ravg_60s = CRR_AVG(60, ravg_60m)            # minutely average bin

    for j in range(86400):
        x = random.randrange(1,100)
        ravg_60s.y(x)
    print("  24 hour average:", ravg_24h.avg)
    print("60 minute average:", ravg_60m.avg)
    print("60 second average:", ravg_60s.avg)

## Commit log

2018-07-10 Added examples
    [v105-1.scad]
2018-10-09 rev1
    Added PCB and support for SGP30
    [AQMmkIIrev1.brd, AQMmkIIrev1.sch]
2019-01-07 Corrected MODBUS configuration and added comments
    [main.py]

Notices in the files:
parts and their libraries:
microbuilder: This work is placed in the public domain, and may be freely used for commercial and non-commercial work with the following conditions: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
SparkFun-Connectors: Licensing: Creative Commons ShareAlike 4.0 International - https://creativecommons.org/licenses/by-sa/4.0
